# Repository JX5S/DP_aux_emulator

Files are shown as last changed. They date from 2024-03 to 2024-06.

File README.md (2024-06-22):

# DP-aux emulator

Hardware design files for a DP-aux emulation board, designed to allow connection of PSVR2 headsets to PC.

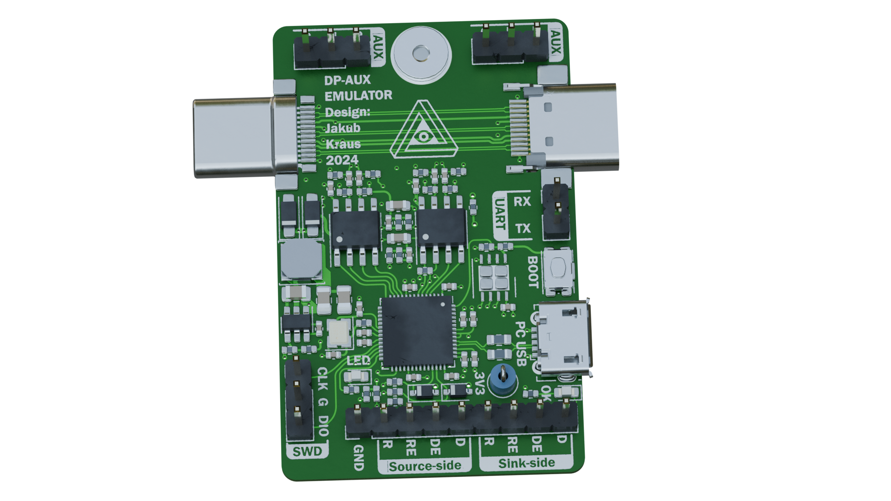
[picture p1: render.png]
(Rendered image using Kicad2blender plugin)


# Why

Prior to a March 2024 update of the PSVR2's firmware, the headset reported incorrect information via DP-aux, among others the EDID and DSC capability. A custom EDID can be set without additional hardware, however DSC options cannot be - so the emulator board was born.

# Status as of June 2024

Since this board was built, Sony released firmware update(s) to the PSVR2, which corrected the lies and allow connection to GPUs directly. While this emulator is still useful for enabling "cinema" mode and for future experiments, such as possibly enabling HDR support, most users won't need it.

This board is only for modifying traffic on DP-aux, it doesn't help if your GPU doesn't have a USB-C port. Sony is releasing an adapter for that soon, I have no reason to believe it wouldn't work with 3rd party drivers.

This is a third revision of the PCB, it has been verified to work as designed.

# Everything you need to build some

## PCBs

The board was designed for JLCPCB's assembly. The necessary files are in the ['Manufacturing data'](https://github.com/JX5S/DP_aux_emulator/tree/main/Manufacturing%20data) folder. The zip file is there for a quick download of just those 3 files. The files are:

- ...-Gerbers.zip = Manufacturing data for the circuit board
- ...-BOM.csv = a list of components that need mounting
- ...-top-pos.csv = a list of positions of each component

The only settings that need changing from defaults during ordering at JLCPCB are PCB thickness (0.8mm) and impedance control (Yes; JLC06081H-2116). Detailed screenshots of all settings including defaults are in the ['JLCPCB settings'](https://github.com/JX5S/DP_aux_emulator/tree/main/JLCPCB%20settings) folder.

The 4th image shows edge-rail cut-outs which need to be added to allow surface mounting of these specific USB-C connectors. These can be added by JLC (you do need to explicitly request them), or you can add them yourself in KiCad, or you can have the edge-rails removed and the USB-C connectors added afterwards (JLC will build a mounting adapter for the board at additional cost).

## Firmware

Firmware was written by the autor of the [iVRy SteamVR driver](https://store.steampowered.com/app/992490). A passthrough-only version of the firmware is provided in this repository for testing, a PSVR2-specific firmware is distributed along with the [iVRy PSVR2 driver](https://store.steampowered.com/app/2772740).

## 3D-Printed case

A case has been designed for the DP-AUX emulator by "Hackinside". They have kindly [made the files available](https://www.pcbway.com/project/shareproject/iVRy_PSVR2_DP_AUX_Emulator_Enclosure_case_ef058b5b.html) for anyone that wants to print their own case.

# How it works

On the PCB is an RP2040 microcontroller, which decides which DP-aux requests to modify and which to pass through unchanged. To interface with DP-aux, a pair of SN65MLVD200A differential transceivers are used. The LVDS part of the circuit is based on Bitec's DisplayPort Daughter Card.

Apart from the core DP-aux emulation circuitry, there is a programming micro-USB connector (I would have used a USB-C, but this way it cannot be confused with the PSVR2 port), orientation detection using USB-C CC pins, and a power section, allowing the board to be powered with either the programming USB port or using VBUS from the USB-Cs. Even though the board was made with specifically the PSVR2 in mind, I tried to make it as compliant as possible with a low part count and it should work well with the maximum voltage of USB-PD3.0, 21V.

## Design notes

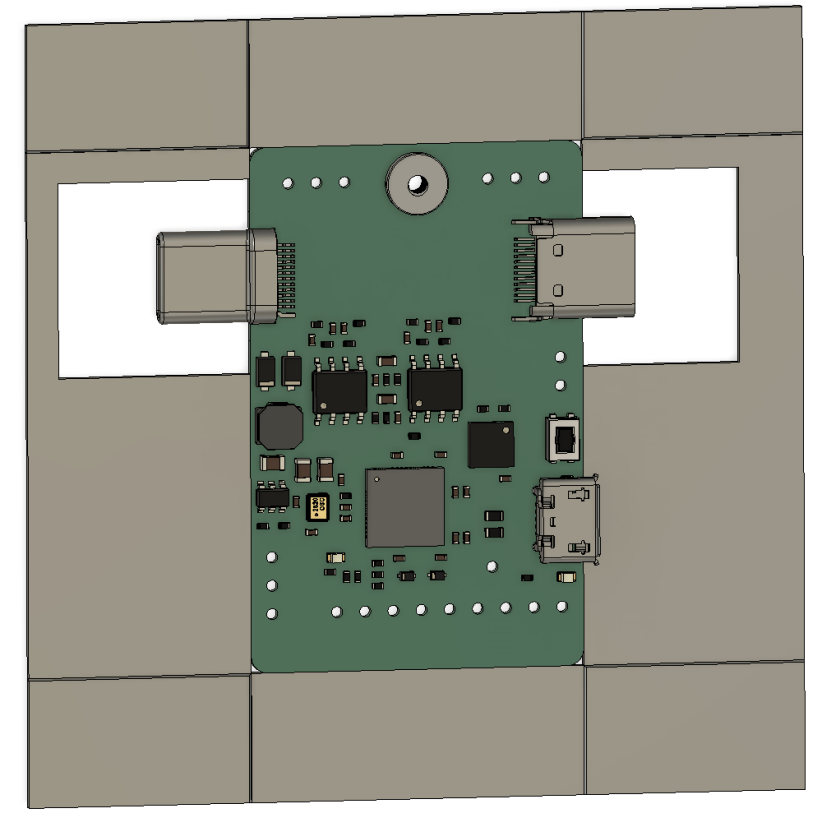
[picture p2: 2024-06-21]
JLCPCB settings/Edge rail example.png

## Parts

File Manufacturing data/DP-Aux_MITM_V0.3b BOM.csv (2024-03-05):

Item | Qty | Reference(s) | Value | LibPart | Footprint | Datasheet | DNP | LCSC | Sim.Device | Sim.Pins
1 | 16 | C1, C4, C5, C10, C11, C12, C13, C14, C15, C16, C18, C19, C21, C22, C23, C24 | 100n | Device:C_Small | Capacitor_SMD:C_0402_1005Metric | ~ |  | C307331
2 | 2 | C2, C3 | 15pF | Device:C_Small | Capacitor_SMD:C_0402_1005Metric | ~ |  | C1548
3 | 4 | C6, C7, C8, C9 | 1uF | Device:C_Small | Capacitor_SMD:C_0402_1005Metric | ~ |  | C52923
4 | 2 | C17, C25 | 10u | Device:C_Small | Capacitor_SMD:C_0603_1608Metric | ~ |  | C19702
5 | 1 | C26 | 10u | Device:C | Capacitor_SMD:C_0805_2012Metric | ~ |  | C15850
6 | 2 | C27, C28 | 22u | Device:C | Capacitor_SMD:C_0805_2012Metric | ~ |  | C45783
7 | 2 | D1, D3 | BZT52-C4V3S | Device:D_Zener_Small | USB-C_for_0.3:D_SOD-323 Panjit | ~ |  | C398771
8 | 2 | D2, D7 | Blue | Device:LED | LED_SMD:LED_0603_1608Metric | ~ |  | C72041
9 | 2 | D4, D5 | SS14 | Device:D_Small | USB-C_for_0.2:D_SOD-123FL | ~ |  | C2909920 | D | 1=K 2=A
11 | 1 | H1 | M2_SMTSO2010CTJ | Mechanical:MountingHole_Pad | M2nutV2:M2 solder nut | https://datasheet.lcsc.com/lcsc/2112061830_Sinhoo-SMTSO2010CTJ_C2916319.pdf |  | C2916319
12 | 1 | J1 | USB_B_Micro | Connector:USB_B_Micro | Connector_USB:USB_Micro-B_Molex-105017-0001 | ~ |  | C132563
15 | 1 | J4 | USB_C_Plug | Connector:USB_C_Receptacle | USB-C_for_0.3:USB_C_VirtualLink_Plug | https://datasheet.lcsc.com/lcsc/2002271811_XKB-Connectivity-U261-241N-4BS60_C319150.pdf |  | C319150
18 | 1 | J8 | USB_C_Receptacle | Connector:USB_C_Receptacle | USB-C_for_0.3:USB_C_Straddle_Socket | https://www.lcsc.com/product-detail/USB-Connectors_HOOYA-USB-307HG-B-SU_C309352.html |  | C309352
22 | 1 | L1 | 15u | Device:L_Small | Inductor_SMD:L_Sunlord_SWPA4018S | ~ |  | C436651
23 | 7 | R1, R7, R8, R9, R17, R18, R28 | 10K | Device:R_Small | Resistor_SMD:R_0402_1005Metric | ~ |  | C25744
24 | 3 | R2, R5, R10 | 1K | Device:R_Small | Resistor_SMD:R_0402_1005Metric | ~ |  | C11702
25 | 2 | R3, R4 | 27R | Device:R_Small | Resistor_SMD:R_0603_1608Metric | ~ |  | C25190
26 | 2 | R6, R19 | 510R | Device:R_Small | Resistor_SMD:R_0402_1005Metric | ~ |  | C25123
27 | 2 | R11, R12 | 1M | Device:R_Small | Resistor_SMD:R_0402_1005Metric | ~ |  | C26083
28 | 4 | R13, R14, R20, R21 | 51R | Device:R_Small | Resistor_SMD:R_0402_1005Metric | ~ |  | C25125
29 | 2 | R15, R24 | 3K3 | Device:R_Small | Resistor_SMD:R_0402_1005Metric | ~ |  | C25890
30 | 2 | R16, R25 | 1K5 | Device:R_Small | Resistor_SMD:R_0402_1005Metric | ~ |  | C25867
31 | 3 | R22, R23, R26 | 100K | Device:R_Small | Resistor_SMD:R_0402_1005Metric | ~ |  | C25741
32 | 1 | R27 | 22K | Device:R_Small | Resistor_SMD:R_0402_1005Metric | ~ |  | C25768
33 | 1 | SW1 | BOOT | Switch:SW_Push | USB-C_for_0.3:C&K KMR223GLFG | ~ |  | C221678
36 | 1 | U1 | W25Q64JVX | Memory_Flash:W25Q128JVS | Package_SON:WSON-8-1EP_4x4mm_P0.8mm_EP2.6x3mm | http://www.winbond.com/resource-files/w25q128jv_dtr%20revc%2003272018%20plus.pdf |  | C2940195
37 | 1 | U2 | RP2040 | MCU_RaspberryPi:RP2040 | Package_DFN_QFN:QFN-56-1EP_7x7mm_P0.4mm_EP3.2x3.2mm | https://datasheets.raspberrypi.com/rp2040/rp2040-datasheet.pdf |  | C2040
38 | 2 | U3, U5 | SN65MLVD200A | diff_transceiver:SN65MLVD200A | Package_SO:SOIC-8_3.9x4.9mm_P1.27mm | https://www.ti.com/lit/ds/symlink/sn65mlvd200a.pdf?ts=1700755286435 |  | SN65MLVD200A
39 | 1 | U6 | TPS54202DDC | Regulator_Switching:TPS54202DDC | Package_TO_SOT_SMD:SOT-23-6 | http://www.ti.com/lit/ds/symlink/tps54202.pdf |  | C191884
40 | 1 | Y1 | 12MHz 12pF | Device:Crystal_GND24_Small | Crystal:Crystal_SMD_2520-4Pin_2.5x2.0mm | https://datasheet.lcsc.com/lcsc/2304140030_YXC-X322512MSB4SI_C9002.pdf |  | C479184

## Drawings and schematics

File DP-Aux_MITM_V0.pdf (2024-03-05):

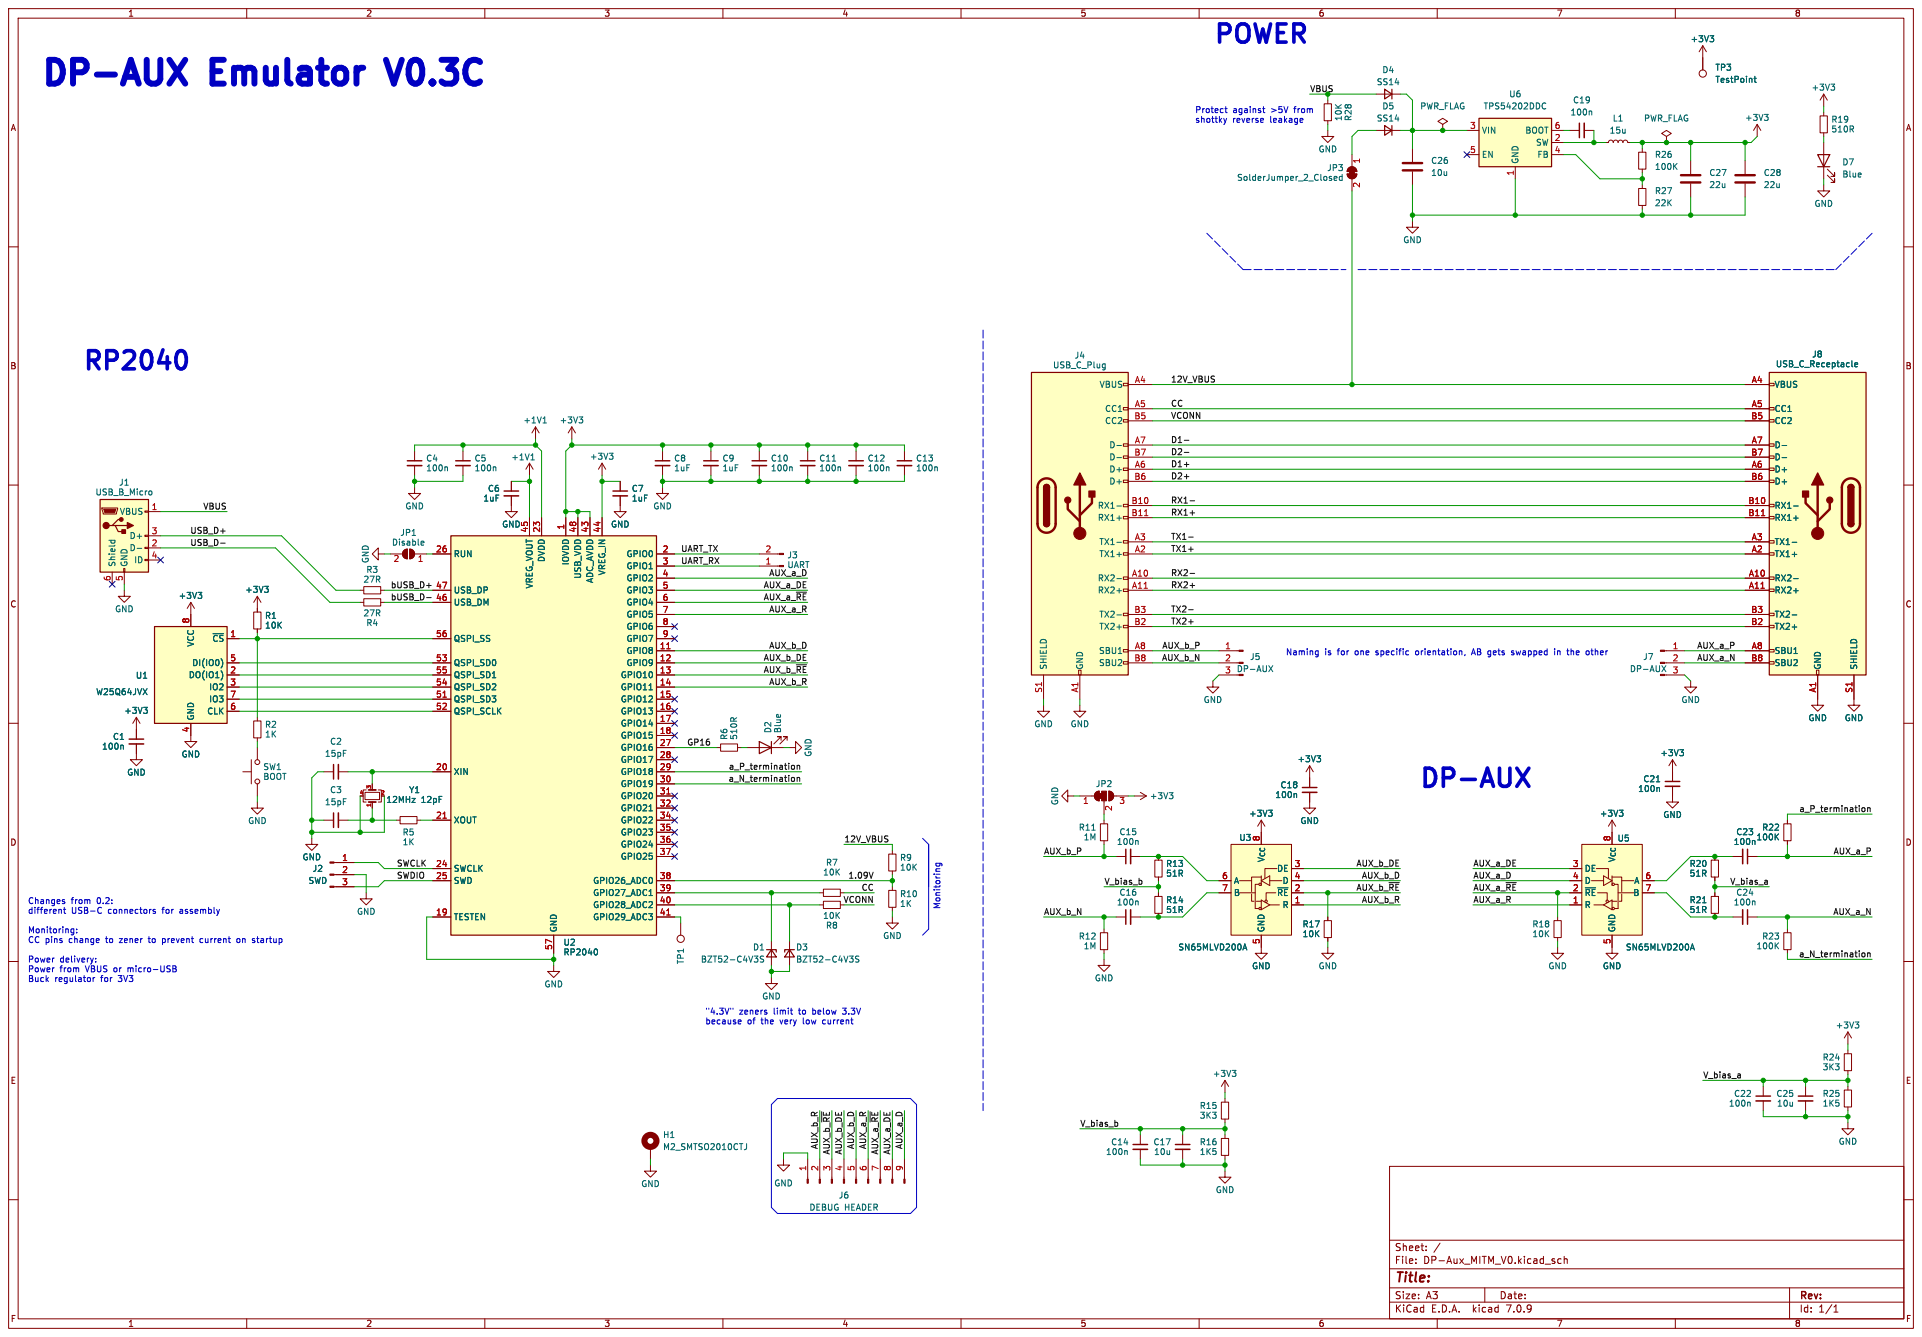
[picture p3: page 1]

1 SW 2 VIN 3 FB 4 EN 5 BOOT 6 U6 TPS54202DDC C19

because of the very low current RP2040

1 GPIO8 11 GPIO9 12 GPIO10 13 GPIO11 14 GPIO12 15 GPIO13 16 GPIO14 17 GPIO15 18 TESTEN 19 GPIO0 2 XIN 20 XOUT 21 DVDD 23 SWCLK 24 SWD 25 RUN 26 GPIO16 27 GPIO17 28 GPIO18 29 GPIO1 3 GPIO19 30 GPIO20 31 GPIO21 32 GPIO22 34 GPIO23 35 GPIO24 36 GPIO25 37 GPIO26_ADC0 38 GPIO27_ADC1 39 GPIO2 4 GPIO28_ADC2 40 GPIO29_ADC3 41 ADC_AVDD 43 VREG_IN 44 VREG_VOUT 45 USB_DM 46 USB_DP 47 USB_VDD 48 GPIO3 5 QSPI_SD3 51 QSPI_SCLK 52 QSPI_SD0 53 QSPI_SD2 54 QSPI_SD1 55 QSPI_SS 56 GND 57 GPIO4 6 GPIO5 7 GPIO6 8 GPIO7 9 U2 RP2040 GND

1 GPIO8 11 GPIO9 12 GPIO10 13 GPIO11 14 GPIO12 15 GPIO13 16 GPIO14 17 GPIO15 18 TESTEN 19 GPIO0 2 XIN 20 XOUT 21 DVDD 23 SWCLK 24 SWD 25 RUN 26 GPIO16 27 GPIO17 28 GPIO18 29 GPIO1 3 GPIO19 30 GPIO20 31 GPIO21 32 GPIO22 34 GPIO23 35 GPIO24 36 GPIO25 37 GPIO26_ADC0 38 GPIO27_ADC1 39 GPIO2 4 GPIO28_ADC2 40 GPIO29_ADC3 41 ADC_AVDD 43 VREG_IN 44 VREG_VOUT 45 USB_DM 46 USB_DP 47 USB_VDD 48 GPIO3 5 QSPI_SD3 51 QSPI_SCLK 52 QSPI_SD0 53 QSPI_SD2 54 QSPI_SD1 55 QSPI_SS 56 GND 57 GPIO4 6 GPIO5 7 GPIO6 8 GPIO7 9 GND

Monitoring: CC pins change to zener to prevent current on startup Power delivery: Power from VBUS or micro-USB

"4.3V" zeners limit to below 3.3V

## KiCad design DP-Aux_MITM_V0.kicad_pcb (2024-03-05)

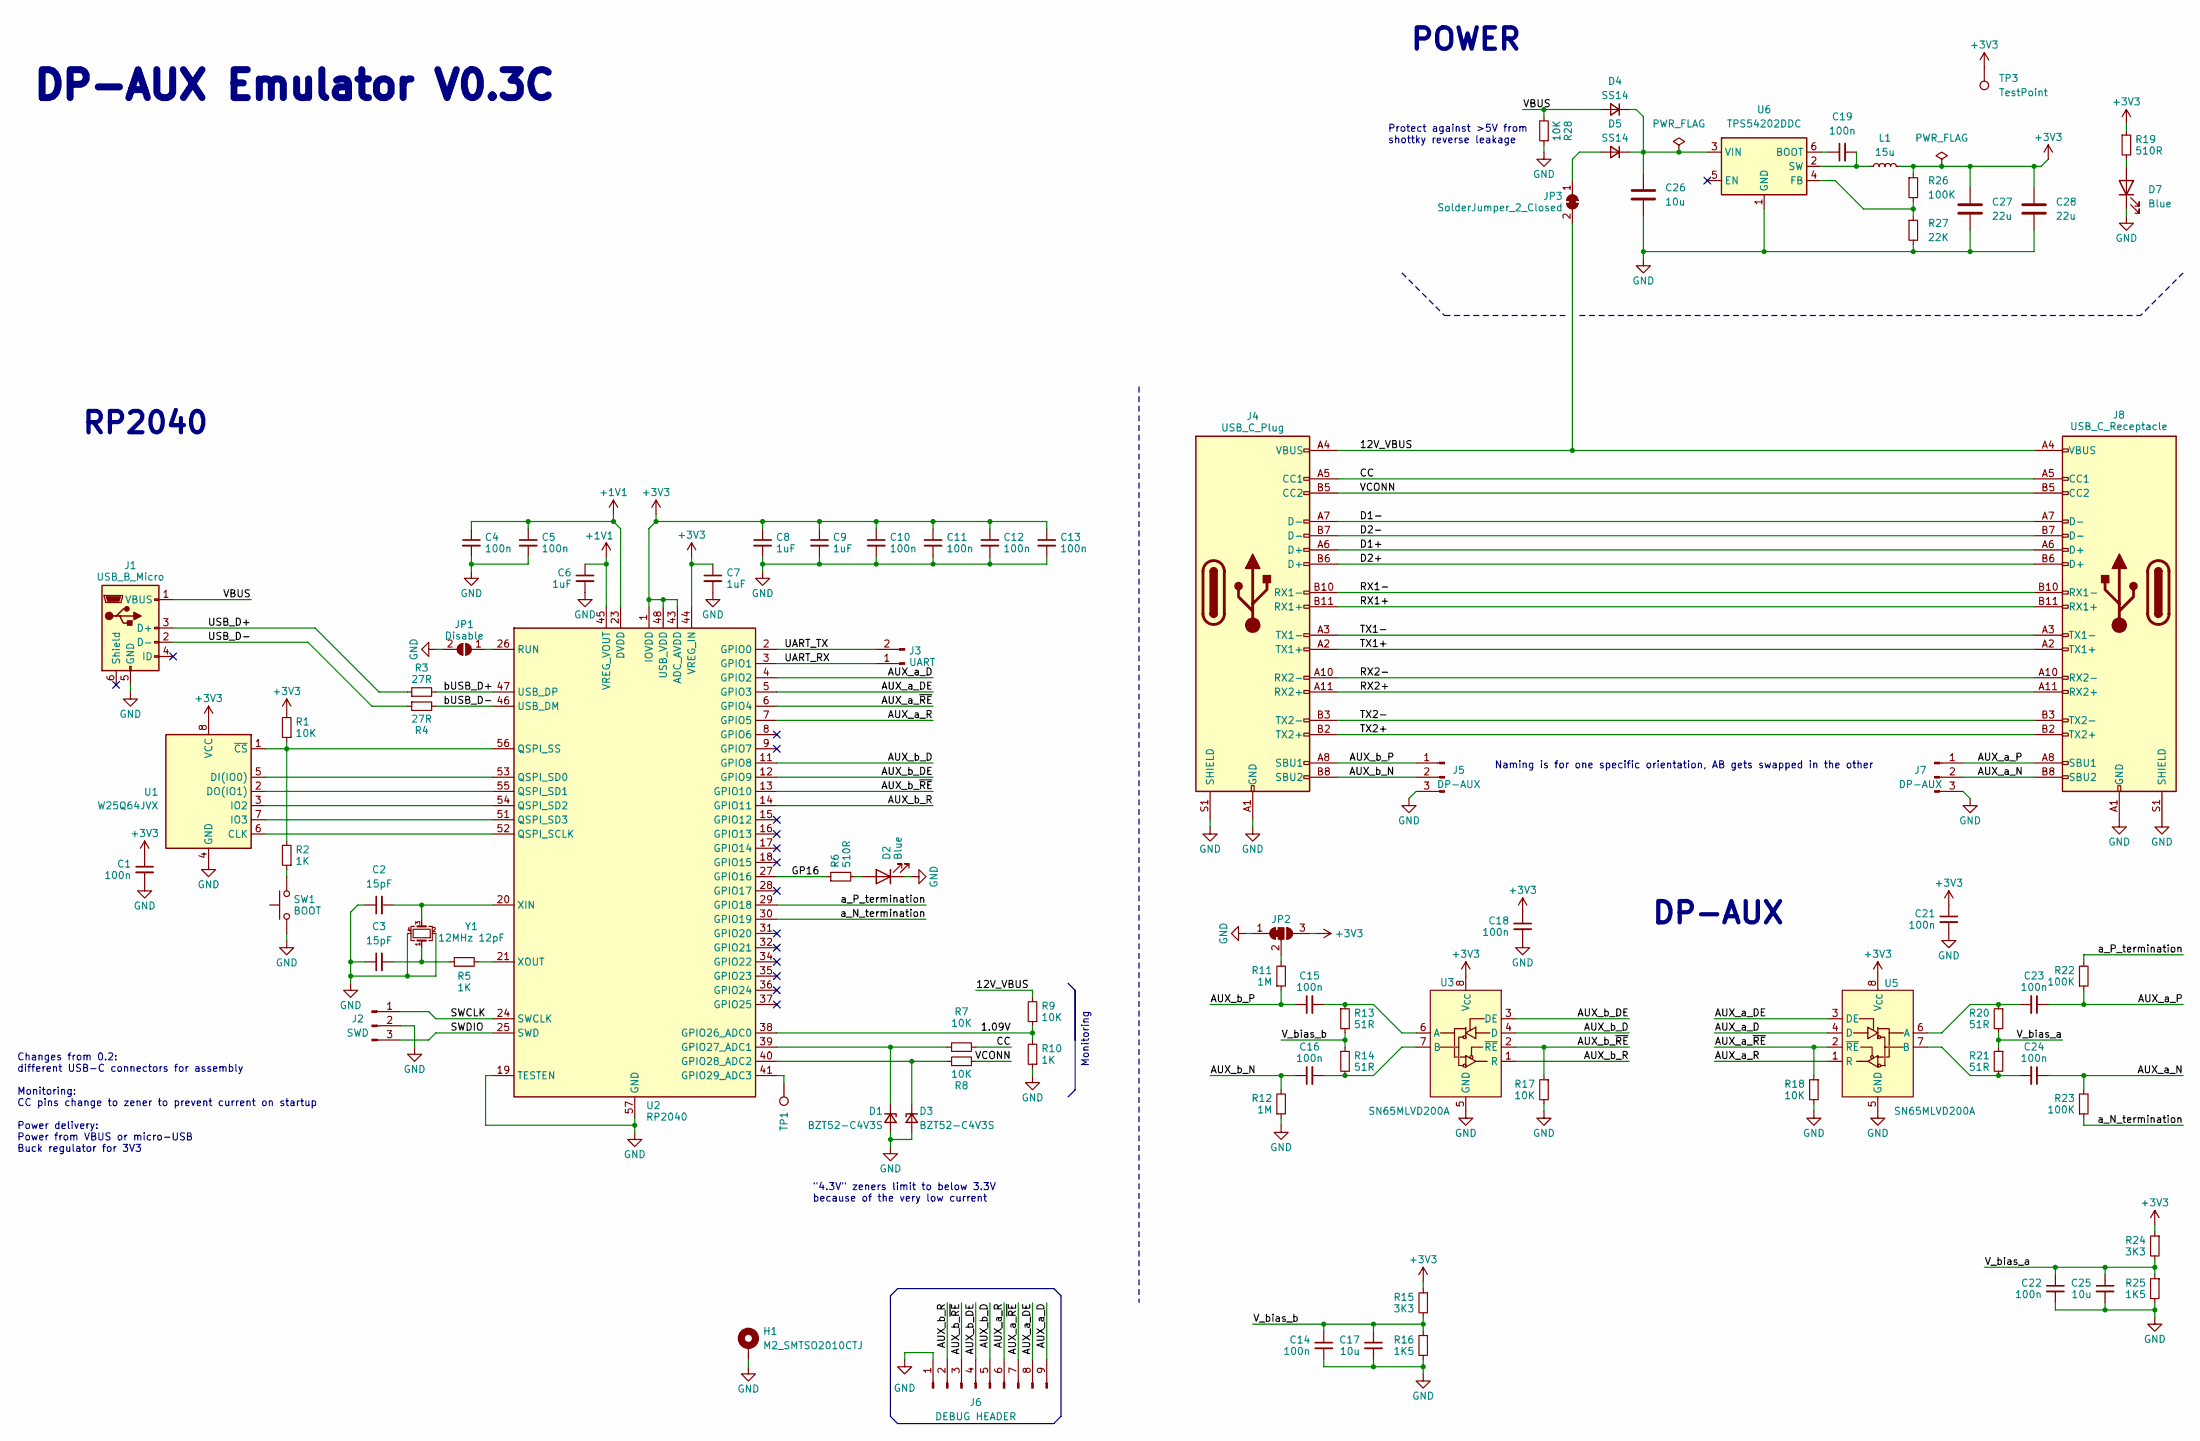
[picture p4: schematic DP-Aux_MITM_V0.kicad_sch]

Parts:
C1, C4, C5, C10, C11, C12, C13, C14, C15, C16, C18, C19, C21, C22, C23, C24: 100n; C_0402_1005Metric; LCSC C307331
C2, C3: 15pF; C_0402_1005Metric; LCSC C1548
C6, C7, C8, C9: 1uF; C_0402_1005Metric; LCSC C52923
C17, C25: 10u; C_0603_1608Metric; LCSC C19702
C26: 10u; C_0805_2012Metric; LCSC C15850
C27, C28: 22u; C_0805_2012Metric; LCSC C45783
D1, D3: BZT52-C4V3S; D_SOD-323 Panjit; LCSC C398771
D2, D7: Blue; LED_0603_1608Metric; LCSC C72041
D4, D5: SS14; D_SOD-123FL; LCSC C2909920
H1: M2_SMTSO2010CTJ; M2 solder nut; LCSC C2916319
J1: USB_B_Micro; USB_Micro-B_Molex-105017-0001; LCSC C132563
J2: SWD; PinHeader_1x03_P2.54mm_Vertical; LCSC DNP
J3: UART; PinHeader_1x02_P2.54mm_Vertical; LCSC DNP
J4: USB_C_Plug; USB_C_VirtualLink_Plug; LCSC C319150
J5, J7: DP-AUX; PinHeader_1x03_P2.54mm_Vertical; LCSC DNP
J6: DEBUG HEADER; PinHeader_1x09_P2.54mm_Vertical; LCSC DNP
J8: USB_C_Receptacle; USB_C_Straddle_Socket; LCSC C309352
JP1: Disable; SolderJumper-2_P1.3mm_Open_RoundedPad1.0x1.5mm; LCSC DNP
JP2: SolderJumper_3_Bridged12; SolderJumper-3_P1.3mm_Bridged2Bar12_RoundedPad1.0x1.5mm; LCSC DNP
JP3: SolderJumper_2_Closed; SolderJumper-2_P1.3mm_Bridged2Bar_RoundedPad1.0x1.5mm; LCSC DNP
L1: 15u; L_Sunlord_SWPA4018S; LCSC C436651
R1, R7, R8, R9, R17, R18, R28: 10K; R_0402_1005Metric; LCSC C25744
R2, R5, R10: 1K; R_0402_1005Metric; LCSC C11702
R3, R4: 27R; R_0603_1608Metric; LCSC C25190
R6, R19: 510R; R_0402_1005Metric; LCSC C25123
R11, R12: 1M; R_0402_1005Metric; LCSC C26083
R13, R14, R20, R21: 51R; R_0402_1005Metric; LCSC C25125
R15, R24: 3K3; R_0402_1005Metric; LCSC C25890
R16, R25: 1K5; R_0402_1005Metric; LCSC C25867
R22, R23, R26: 100K; R_0402_1005Metric; LCSC C25741
R27: 22K; R_0402_1005Metric; LCSC C25768
SW1: BOOT; C&K KMR223GLFG; LCSC C221678
TP1: TestPoint; TestPoint_Pad_D2.0mm; LCSC DNP
TP3: TestPoint; TestPoint_Loop_D1.80mm_Drill1.0mm_Beaded; LCSC C238122
U1: W25Q64JVX; WSON-8-1EP_4x4mm_P0.8mm_EP2.6x3mm; LCSC C2940195
U2: RP2040; QFN-56-1EP_7x7mm_P0.4mm_EP3.2x3.2mm; LCSC C2040
U3, U5: SN65MLVD200A; SOIC-8_3.9x4.9mm_P1.27mm; LCSC SN65MLVD200A
U6: TPS54202DDC; SOT-23-6; LCSC C191884
Y1: 12MHz 12pF; Crystal_SMD_2520-4Pin_2.5x2.0mm; LCSC C479184

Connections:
+1V1: C4.1, C5.1, C6.1, U2.23 (DVDD), U2.45 (VREG_VOUT), U2.50 (DVDD)
+3V3: C1.1, C7.1, C8.1, C9.1, C10.1, C11.1, C12.1, C13.1, C18.1, C21.1, C27.1, C28.1, JP2.3 (B), L1.2, R1.2, R15.1, R19.1, R24.1, R26.1, TP3.1, U1.8 (VCC), U2.1 (IOVDD), U2.10 (IOVDD), U2.22 (IOVDD), U2.33 (IOVDD), U2.42 (IOVDD), U2.43 (ADC_AVDD), U2.44 (VREG_IN), U2.48 (USB_VDD), U2.49 (IOVDD), U3.8 (V_{CC}), U5.8 (V_{CC})
/1.09V: R9.1, R10.2, U2.38 (GPIO26_ADC0)
/12V_VBUS: J4.A4 (VBUS), J4.A9 (VBUS), J4.B4 (VBUS), J4.B9 (VBUS), J8.A4 (VBUS), J8.A9 (VBUS), J8.B4 (VBUS), J8.B9 (VBUS), JP3.2 (B), R9.2
/AUX_a_D: J6.9, U2.4 (GPIO2), U5.4 (D)
/AUX_a_DE: J6.8, U2.5 (GPIO3), U5.3 (DE)
/AUX_a_N: C24.1, J7.2, J8.B8 (SBU2), R23.2
/AUX_a_P: C23.1, J7.1, J8.A8 (SBU1), R22.1
/AUX_a_R: J6.6, U2.7 (GPIO5), U5.1 (R)
/AUX_a_~RE: J6.7, R18.1, U2.6 (GPIO4), U5.2 (~RE)
/AUX_b_D: J6.5, U2.11 (GPIO8), U3.4 (D)
/AUX_b_DE: J6.4, U2.12 (GPIO9), U3.3 (DE)
/AUX_b_N: C16.1, J4.B8 (SBU2), J5.2, R12.2
/AUX_b_P: C15.1, J4.A8 (SBU1), J5.1, R11.1
/AUX_b_R: J6.2, U2.14 (GPIO11), U3.1 (R)
/AUX_b_~RE: J6.3, R17.1, U2.13 (GPIO10), U3.2 (~RE)
/CC: J4.A5 (CC1), J8.A5 (CC1), R7.2
/D1+: J4.A6 (D+), J8.A6 (D+)
/D1-: J4.A7 (D-), J8.A7 (D-)
/D2+: J4.B6 (D+), J8.B6 (D+)
/D2-: J4.B7 (D-), J8.B7 (D-)
/GP16: R6.1, U2.27 (GPIO16)
/RX1+: J4.B11 (RX1+), J8.B11 (RX1+)
/RX1-: J4.B10 (RX1-), J8.B10 (RX1-)
/RX2+: J4.A11 (RX2+), J8.A11 (RX2+)
/RX2-: J4.A10 (RX2-), J8.A10 (RX2-)
/SWCLK: J2.1, U2.24 (SWCLK)
/SWDIO: J2.3, U2.25 (SWD)
/TX1+: J4.A2 (TX1+), J8.A2 (TX1+)
/TX1-: J4.A3 (TX1-), J8.A3 (TX1-)
/TX2+: J4.B2 (TX2+), J8.B2 (TX2+)
/TX2-: J4.B3 (TX2-), J8.B3 (TX2-)
/UART_RX: J3.1, U2.3 (GPIO1)
/UART_TX: J3.2, U2.2 (GPIO0)
/USB_D+: J1.3 (D+), R3.1
/USB_D-: J1.2 (D-), R4.1
/VBUS: D4.2 (A), J1.1 (VBUS), R28.2
/VCONN: J4.B5 (CC2), J8.B5 (CC2), R8.2
/V_bias_a: C22.1, C25.1, R20.2, R21.1, R24.2, R25.1
/V_bias_b: C14.1, C17.1, R13.2, R14.1, R15.2, R16.1
/a_N_termination: R23.1, U2.30 (GPIO19)
/a_P_termination: R22.2, U2.29 (GPIO18)
/bUSB_D+: R3.2, U2.47 (USB_DP)
/bUSB_D-: R4.2, U2.46 (USB_DM)
GND: C1.2, C2.1, C3.1, C4.2, C5.2, C6.2, C7.2, C8.2, C9.2, C10.2, C11.2, C12.2, C13.2, C14.2, C17.2, C18.2, C21.2, C22.2, C25.2, C26.2, C27.2, C28.2, D1.2 (A), D2.1 (K), D3.2 (A), D7.1 (K), H1.1, J1.5 (GND), J2.2, J4.A1 (GND), J4.A12 (GND), J4.B1 (GND), J4.B12 (GND), J4.S1 (SHIELD), J5.3, J6.1, J7.3, J8.A1 (GND), J8.A12 (GND), J8.B1 (GND), J8.B12 (GND), J8.S1 (SHIELD), JP1.2 (B), JP2.1 (A), R10.1, R12.1, R16.2, R17.2, R18.2, R25.2, R27.2, R28.1, SW1.1, U1.4 (GND), U2.19 (TESTEN), U2.57 (GND), U3.5 (GND), U5.5 (GND), U6.1 (GND), Y1.2, Y1.4
unnamed: C3.2, R5.1, Y1.1
unnamed: D1.1 (K), R7.1, U2.39 (GPIO27_ADC1)
unnamed: D2.2 (A), R6.2
unnamed: D3.1 (K), R8.1, U2.40 (GPIO28_ADC2)
unnamed: C26.1, D4.1 (K), D5.1 (K), U6.3 (VIN)
unnamed: D5.2 (A), JP3.1 (A)
unnamed: D7.2 (A), R19.2
unnamed: JP1.1 (A), U2.26 (RUN)
unnamed: JP2.2 (C), R11.2
unnamed: R2.1, SW1.2
unnamed: U1.6 (CLK), U2.52 (QSPI_SCLK)
unnamed: U1.5 (DI(IO0)), U2.53 (QSPI_SD0)
unnamed: U1.2 (DO(IO1)), U2.55 (QSPI_SD1)
unnamed: U1.3 (IO2), U2.54 (QSPI_SD2)
unnamed: U1.7 (IO3), U2.51 (QSPI_SD3)
unnamed: R1.1, R2.2, U1.1 (~CS), U2.56 (QSPI_SS)
unnamed: TP1.1, U2.41 (GPIO29_ADC3)
unnamed: C2.2, U2.20 (XIN), Y1.3
unnamed: R5.2, U2.21 (XOUT)
unnamed: C15.2, R13.1, U3.6 (A)
unnamed: C16.2, R14.2, U3.7 (B)
unnamed: C23.2, R20.1, U5.6 (A)
unnamed: C24.2, R21.2, U5.7 (B)
unnamed: C19.1, U6.6 (BOOT)
unnamed: R26.2, R27.1, U6.4 (FB)
unnamed: C19.2, L1.1, U6.2 (SW)

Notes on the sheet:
RP2040
DP-AUX
Naming is for one specific orientation, AB gets swapped in the other
Changes from 0.2: different USB-C connectors for assembly Monitoring: CC pins change to zener to prevent current on startup Power delivery: Power from VBUS or micro-USB Buck regulator for 3V3
Protect against >5V from shottky reverse leakage
POWER
DP-AUX Emulator V0.3C
Monitoring
"4.3V" zeners limit to below 3.3V because of the very low current

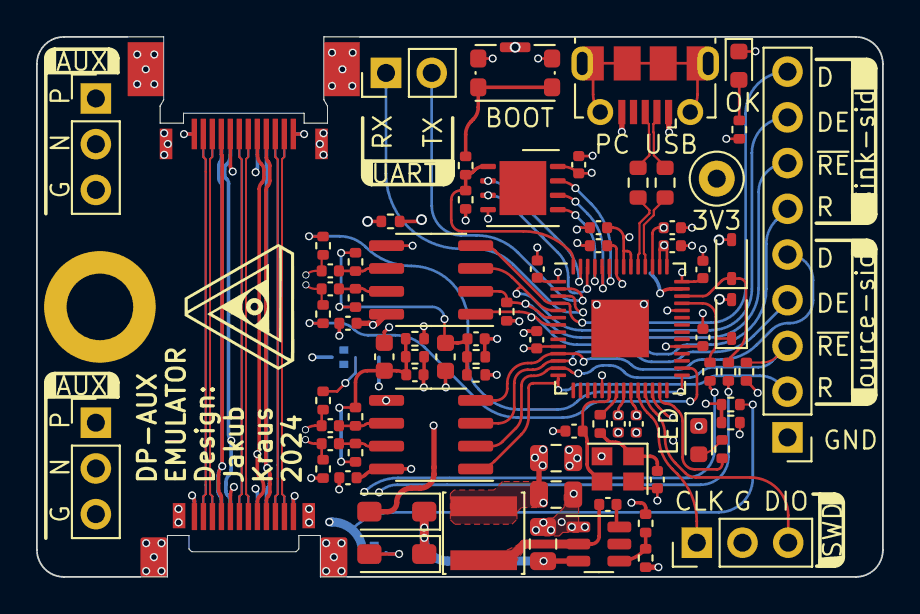
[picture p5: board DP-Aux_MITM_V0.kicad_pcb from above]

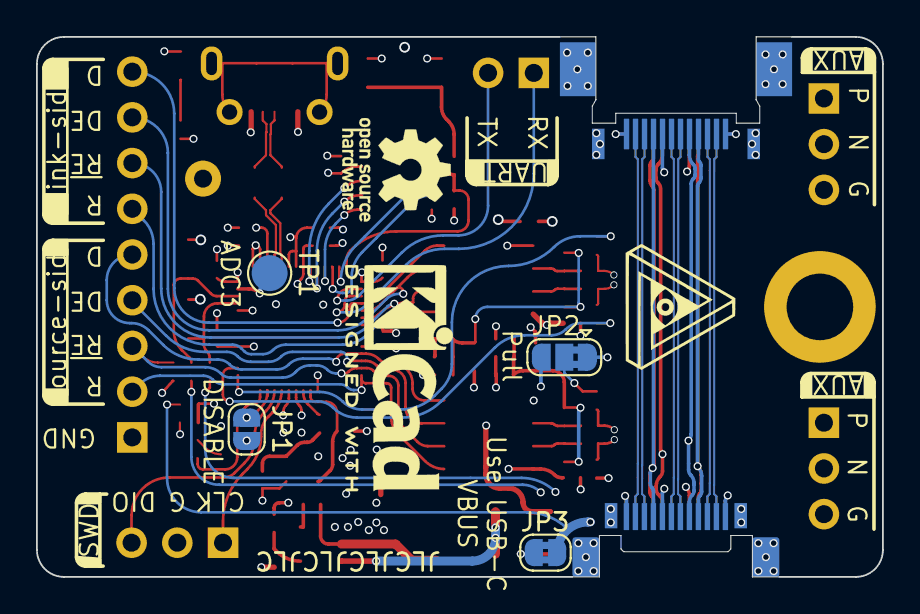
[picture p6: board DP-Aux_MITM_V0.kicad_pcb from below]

Board: 6 copper layers, 47.0 x 30.0 mm, 83 parts (4 on the bottom side), 71 nets.
